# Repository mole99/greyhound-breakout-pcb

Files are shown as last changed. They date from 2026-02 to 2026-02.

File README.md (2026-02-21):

# Greyhound Breakout PCB

This repository holds the breakout PCB for [Greyhound](https://github.com/mole99/greyhound-ihp).
It was designed for [Greyhound v1](https://github.com/mole99/greyhound-ihp-v1) taped out on 07 Apr 2025, SG13G2.

<p align="center">
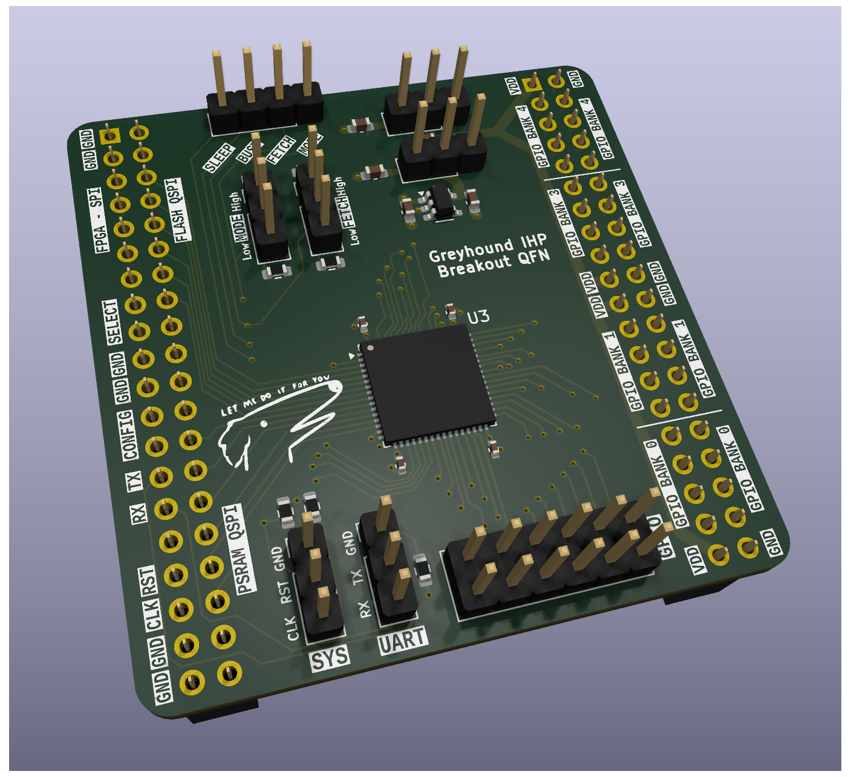
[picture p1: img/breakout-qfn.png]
PCB

</p>

It is based on the [Tiny Tapeout breakout](https://github.com/TinyTapeout/breakout-pcb) board. Thanks a lot!

The PCB was designed with KiCad version 9.0.

Check out the project in your browser using KiCanvas: [Greyhound Breakout PCB](https://kicanvas.org/?github=https://github.com/mole99/greyhound-breakout-pcb/blob/main/breakout-qfn.kicad_pro)

# License

The PCB is licensed under the Apache 2 License

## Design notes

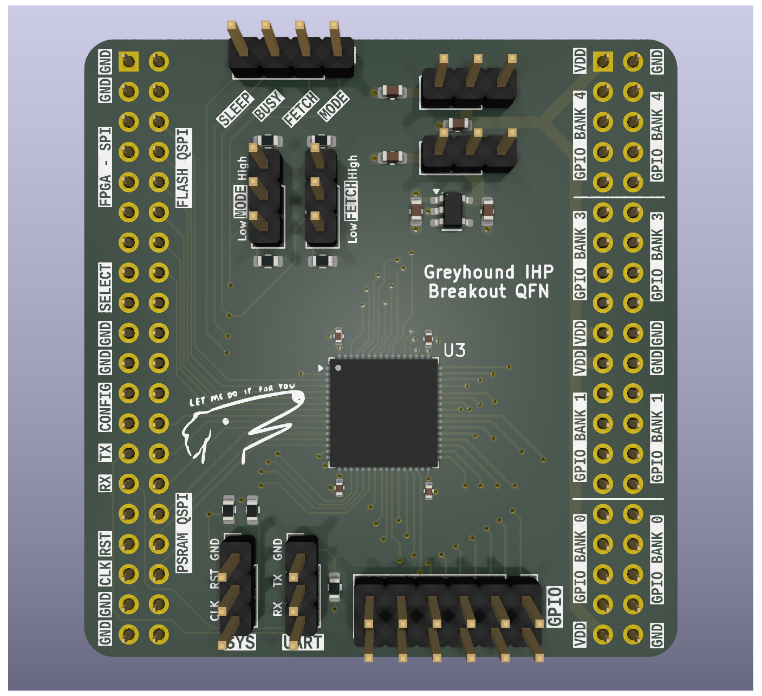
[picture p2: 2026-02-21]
img/breakout-qfn_front.png

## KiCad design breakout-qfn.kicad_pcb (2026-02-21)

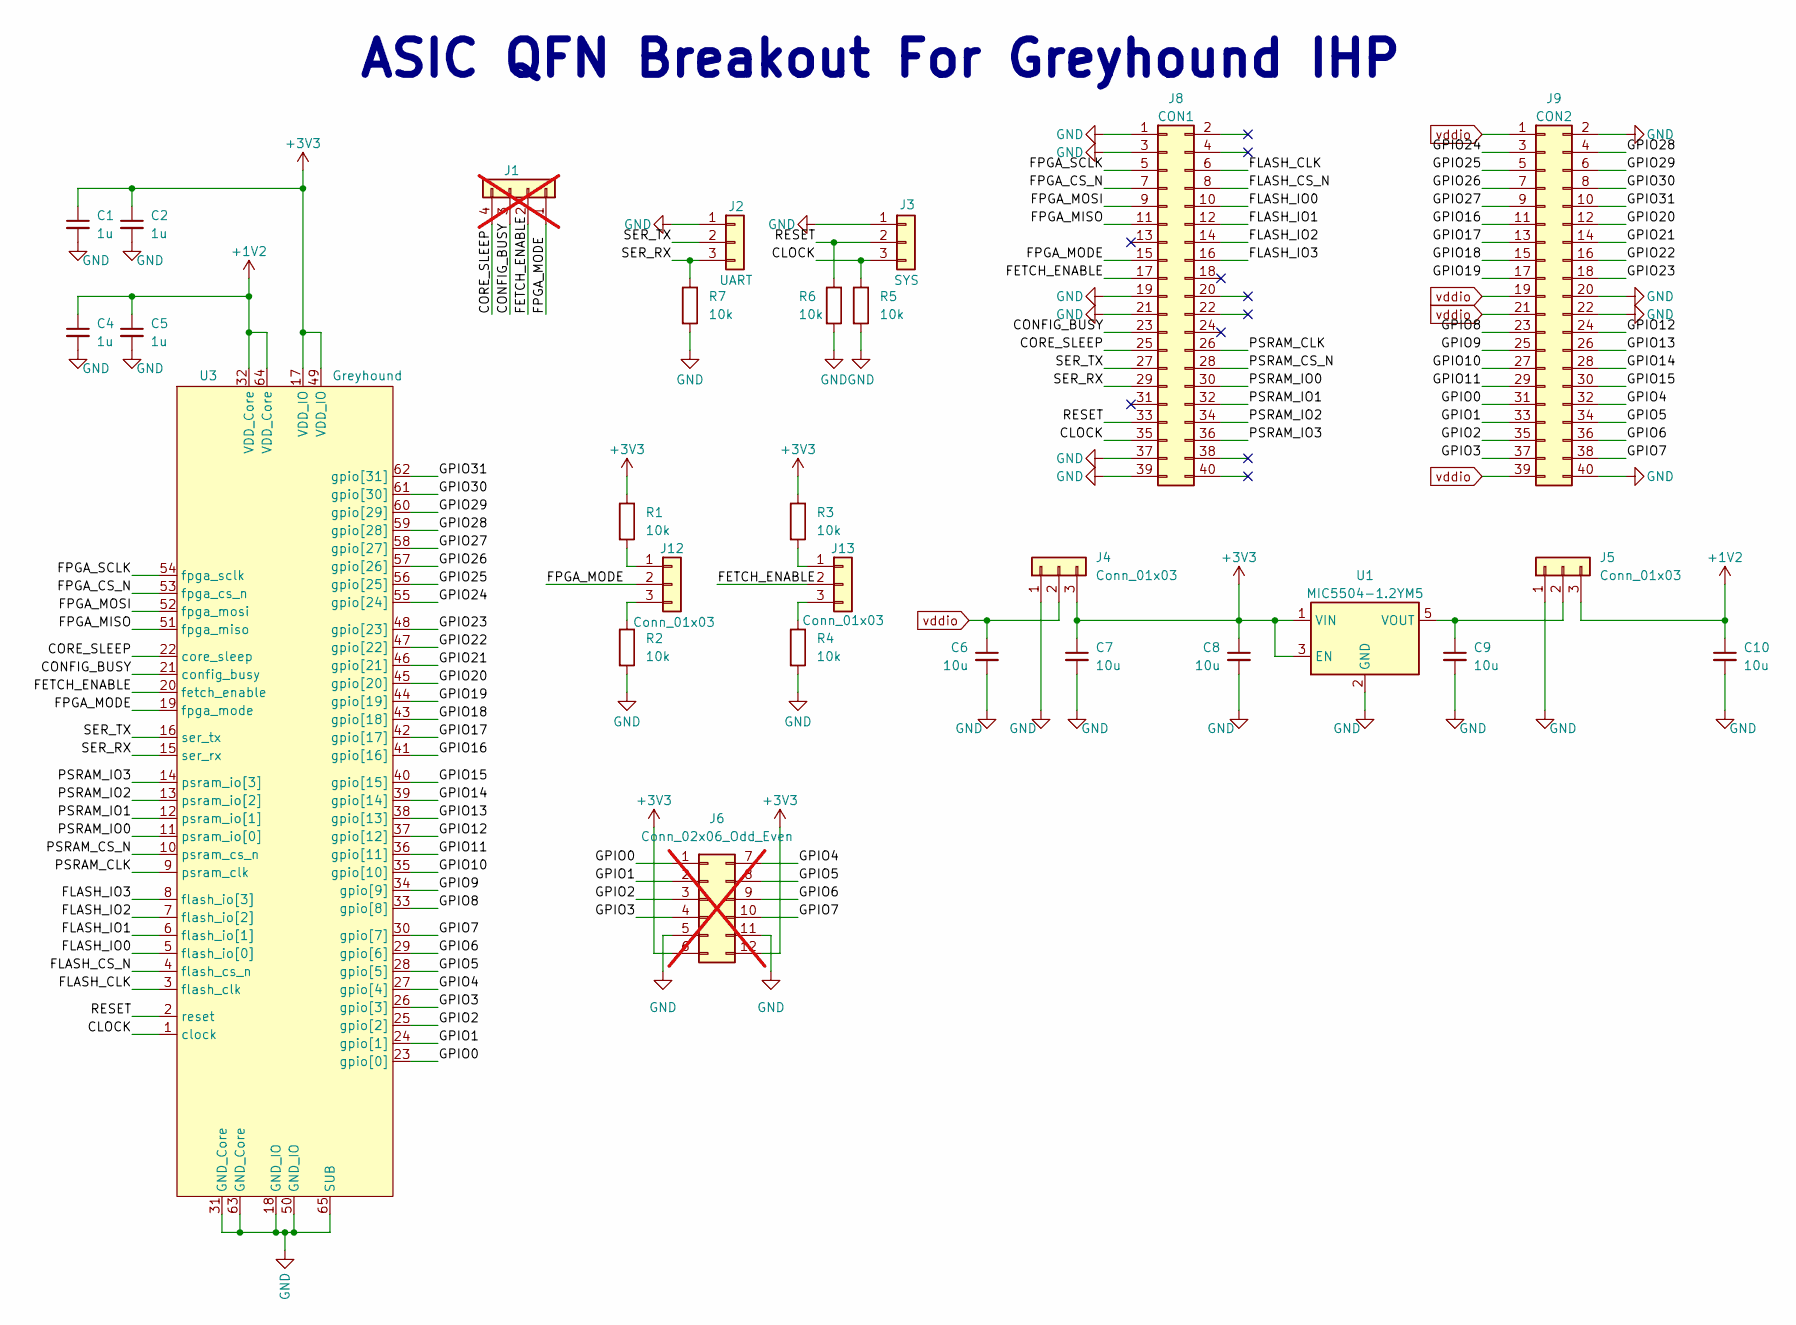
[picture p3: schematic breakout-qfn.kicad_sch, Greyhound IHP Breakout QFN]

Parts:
C1, C2, C4, C5: 1u; C_0402_1005Metric
C6, C7, C8, C9, C10: 10u; C_0603_1608Metric
J1: Conn_01x04; PinHeader_1x04_P2.54mm_Vertical; not fitted
J2: UART; PinHeader_1x03_P2.54mm_Vertical
J3: SYS; PinHeader_1x03_P2.54mm_Vertical
J4, J5, J12, J13: Conn_01x03; PinHeader_1x03_P2.54mm_Vertical
J6: Conn_02x06_Odd_Even; PinHeader_2x06_P2.54mm_Vertical; not fitted
J8: CON1; PinSocket_2x20_P2.54mm_Vertical
J9: CON2; PinSocket_2x20_P2.54mm_Vertical
R1, R2, R3, R4, R5, R6, R7: 10k; R_0603_1608Metric; LCSC C202394
U1: MIC5504-1.2YM5; SOT-23-5
U3: Greyhound; QFN-64-1EP_9x9mm_P0.5mm_EP6x6mm

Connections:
+1V2: C4.1, C5.1, C10.1, J5.3, U3.32 (VDD_Core), U3.64 (VDD_Core)
+3V3: C1.1, C2.1, C7.1, C8.1, J4.3, J6.6, J6.12, R1.1, R3.1, U1.1 (VIN), U1.3 (EN), U3.17 (VDD_IO), U3.49 (VDD_IO)
/CLOCK: J3.3, J8.35, R5.1, U3.1 (clock)
/CONFIG_BUSY: J1.3, J8.23, U3.21 (config_busy)
/CORE_SLEEP: J1.4, J8.25, U3.22 (core_sleep)
/FETCH_ENABLE: J1.2, J8.17, J13.2, U3.20 (fetch_enable)
/FLASH_CLK: J8.6, U3.3 (flash_clk)
/FLASH_CS_N: J8.8, U3.4 (flash_cs_n)
/FLASH_IO0: J8.10, U3.5 (flash_io[0])
/FLASH_IO1: J8.12, U3.6 (flash_io[1])
/FLASH_IO2: J8.14, U3.7 (flash_io[2])
/FLASH_IO3: J8.16, U3.8 (flash_io[3])
/FPGA_CS_N: J8.7, U3.53 (fpga_cs_n)
/FPGA_MISO: J8.11, U3.51 (fpga_miso)
/FPGA_MODE: J1.1, J8.15, J12.2, U3.19 (fpga_mode)
/FPGA_MOSI: J8.9, U3.52 (fpga_mosi)
/FPGA_SCLK: J8.5, U3.54 (fpga_sclk)
/GPIO0: J6.1, J9.31, U3.23 (gpio[0])
/GPIO1: J6.2, J9.33, U3.24 (gpio[1])
/GPIO2: J6.3, J9.35, U3.25 (gpio[2])
/GPIO3: J6.4, J9.37, U3.26 (gpio[3])
/GPIO4: J6.7, J9.32, U3.27 (gpio[4])
/GPIO5: J6.8, J9.34, U3.28 (gpio[5])
/GPIO6: J6.9, J9.36, U3.29 (gpio[6])
/GPIO7: J6.10, J9.38, U3.30 (gpio[7])
/GPIO8: J9.23, U3.33 (gpio[8])
/GPIO9: J9.25, U3.34 (gpio[9])
/GPIO10: J9.27, U3.35 (gpio[10])
/GPIO11: J9.29, U3.36 (gpio[11])
/GPIO12: J9.24, U3.37 (gpio[12])
/GPIO13: J9.26, U3.38 (gpio[13])
/GPIO14: J9.28, U3.39 (gpio[14])
/GPIO15: J9.30, U3.40 (gpio[15])
/GPIO16: J9.11, U3.41 (gpio[16])
/GPIO17: J9.13, U3.42 (gpio[17])
/GPIO18: J9.15, U3.43 (gpio[18])
/GPIO19: J9.17, U3.44 (gpio[19])
/GPIO20: J9.12, U3.45 (gpio[20])
/GPIO21: J9.14, U3.46 (gpio[21])
/GPIO22: J9.16, U3.47 (gpio[22])
/GPIO23: J9.18, U3.48 (gpio[23])
/GPIO24: J9.3, U3.55 (gpio[24])
/GPIO25: J9.5, U3.56 (gpio[25])
/GPIO26: J9.7, U3.57 (gpio[26])
/GPIO27: J9.9, U3.58 (gpio[27])
/GPIO28: J9.4, U3.59 (gpio[28])
/GPIO29: J9.6, U3.60 (gpio[29])
/GPIO30: J9.8, U3.61 (gpio[30])
/GPIO31: J9.10, U3.62 (gpio[31])
/PSRAM_CLK: J8.26, U3.9 (psram_clk)
/PSRAM_CS_N: J8.28, U3.10 (psram_cs_n)
/PSRAM_IO0: J8.30, U3.11 (psram_io[0])
/PSRAM_IO1: J8.32, U3.12 (psram_io[1])
/PSRAM_IO2: J8.34, U3.13 (psram_io[2])
/PSRAM_IO3: J8.36, U3.14 (psram_io[3])
/RESET: J3.2, J8.33, R6.1, U3.2 (reset)
/SER_RX: J2.3, J8.29, R7.1, U3.15 (ser_rx)
/SER_TX: J2.2, J8.27, U3.16 (ser_tx)
GND: C1.2, C2.2, C4.2, C5.2, C6.2, C7.2, C8.2, C9.2, C10.2, J2.1, J3.1, J4.1, J5.1, J6.5, J6.11, J8.1, J8.3, J8.19, J8.21, J8.37, J8.39, J9.2, J9.20, J9.22, J9.40, R2.2, R4.2, R5.2, R6.2, R7.2, U1.2 (GND), U3.18 (GND_IO), U3.31 (GND_Core), U3.50 (GND_IO), U3.63 (GND_Core), U3.65 (SUB)
unnamed: C9.1, J5.2, U1.5 (VOUT)
unnamed: J12.1, R1.2
unnamed: J12.3, R2.1
unnamed: J13.1, R3.2
unnamed: J13.3, R4.1
vddio: C6.1, J4.2, J9.1, J9.19, J9.21, J9.39

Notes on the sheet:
ASIC QFN Breakout For Greyhound IHP

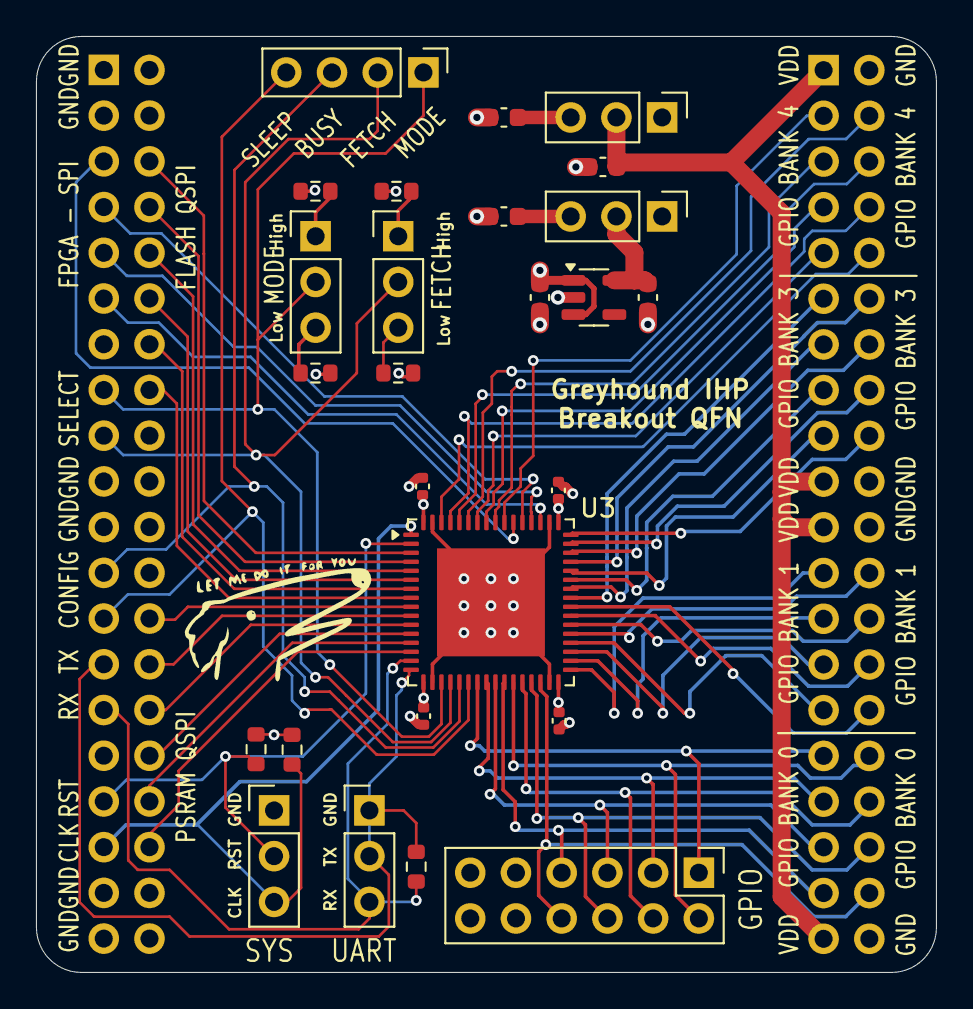
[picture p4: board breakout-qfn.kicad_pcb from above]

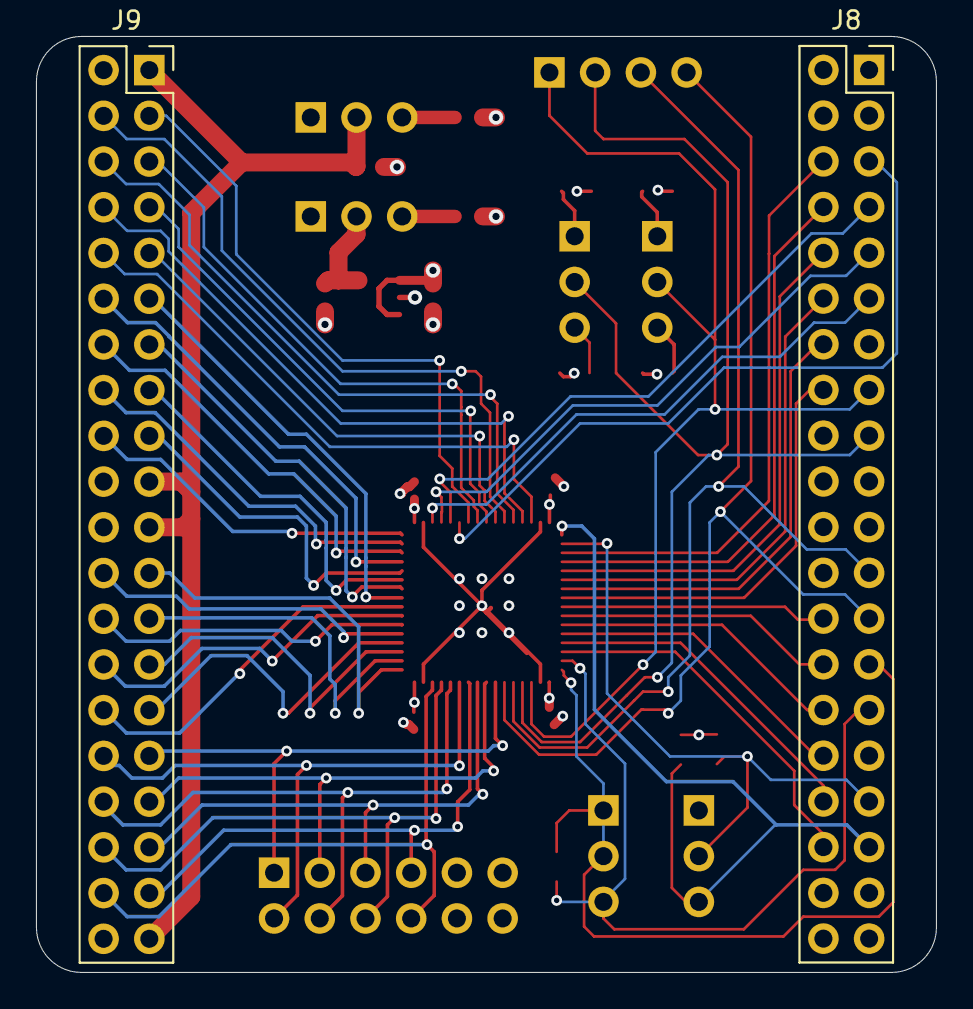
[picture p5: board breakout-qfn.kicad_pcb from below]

Board: 4 copper layers, 50.0 x 52.0 mm, 28 parts (2 on the bottom side), 65 nets.

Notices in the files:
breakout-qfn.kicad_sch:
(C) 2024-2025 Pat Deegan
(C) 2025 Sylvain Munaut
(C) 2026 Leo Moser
